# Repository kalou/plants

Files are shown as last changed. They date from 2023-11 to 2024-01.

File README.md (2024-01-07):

# Plants
*Plants monitoring and watering*

## Description

Plants is composed of:
* A sensor monitoring system and water pumps controller, written in Python, that
  runs on Linux, likely a Pi:
* Some [hardware](./hw) including a Raspberry Pi hat, switches and sensors.

## Features
### Supported sensors
* Support for ADS1115 ADC, to read voltage level sensors such as standard 555-based capacitive moisture sensors.
* Support for [chirp](https://github.com/Miceuz/i2c-moisture-sensor) i2c sensors, reading temperature and moisture.
### Watering
* Configuration and rule based watering:
  - Triggering watering based on sensor humidity percentage.
  - Watering limits per pump, persisted to disk.
* API to manually trigger watering.
### Metrics
* Export of sensor and pump data metrics to prometheus.
* API to poll running config and basic values.
## Example configuration
```
# Plants configuration

# For prometheus, and API, listen on public interface:
host: 0.0.0.0
port: 9191

# How frequently to poll
poll_interval: 5s

sensor_groups:
  -
    kind: 'chirp'   # Got a chirp for temp metrics
  -
    kind: 'ads1115'
    smbus: 1             # i2c BUS to reach the board, default 1 on rpi
    i2c_address: 72      # Address of the ADS1115
    enable_port: 9       # GPIO turning the group on
    sensors:
      - Dragon tail: &cap_sensor
          voltage_dry: 2.62 # This model has a better oscillator
          voltage_wet: 1.23 # and calibrates differently.
          port: 2
      #- Sensor 1: &bad555_cap_sensor
      #    <<: *cap_sensor
      #    voltage_dry: 2.05  # Than this one, where they used an
      #    voltage_wet: 0.95  # ne555.
      #    port: 2
      - Willows:
          <<: *cap_sensor
          port: 3
      - Small money trees:
          <<: *cap_sensor
          port: 1
      - Pothos:
          <<: *cap_sensor
          port: 0
  -
    kind: 'ads1115'
    smbus: 1             # i2c BUS to reach the board, default 1 on rpi
    i2c_address: 72      # Address of the ADS1115
    enable_port: 11      # GPIO turning the group on
    sensors:
      - Money tree:
          <<: *cap_sensor
          port: 3
      - Lemon tree:
          <<: *cap_sensor
          port: 2
      - Bonsai soil:
          <<: *cap_sensor
          port: 1
      - Parlor palm:
          <<: *cap_sensor
          port: 0

# If configured, pump history is saved across restarts
# in sqlite3 db. Otherwise, in-memory watering limits
# are used.
pumps_history_db: /var/lib/plants/plants_pumps_state.db

pumps:
  - Plants to the left:    # Pump 0
      kind: 'gpio'
      port: 10             # GPIO port activates pump on high
      duration: 20s        # Activate for 20s
      limits: &pump_limits
        - per_interval: 2w
          duration: 40s
        - per_interval: 300s
          duration: 20s
      activation_thresholds:
        - Money tree: 50% 
        - Pothos: 50% 
  - Shelf 1:               # Pump 1
      kind: 'gpio'
      port: 17
      duration: 20s
      limits: *pump_limits
      activation_thresholds:
        - Small money trees: 50%
        - Parlor palm: 50% 
  - Dragon tail:
      kind: 'gpio'         # Pump 2
      port: 22             # GPIO port activates pump on high
      duration: 20s
      limits: *pump_limits
      activation_thresholds:
        - Dragon tail: 50%  
  - Shelf 2:               # Pump 3 
      kind: 'gpio'
      port: 27             # GPIO port activates pump on high
      duration: 20s
      limits: *pump_limits
      activation_thresholds:
        - Lemon tree: 50%
        - Willows: 60%
```

## Developement
### Setup and local experiments
```
bash$ pip install -r requirements.txt
bash$ pip install --editable .
bash$ plants_server -c plants/plants.yaml
```
### Various helpers
```
bash$ python -m unittest discover plants
bash$ black plants # auto format
bash$ pylint plants
```


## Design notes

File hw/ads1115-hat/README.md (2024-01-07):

# Plants hat
*Disclaimer: I'm using this project to learn electronics. Use at your own risks and feel free
to reach out with suggestions.*

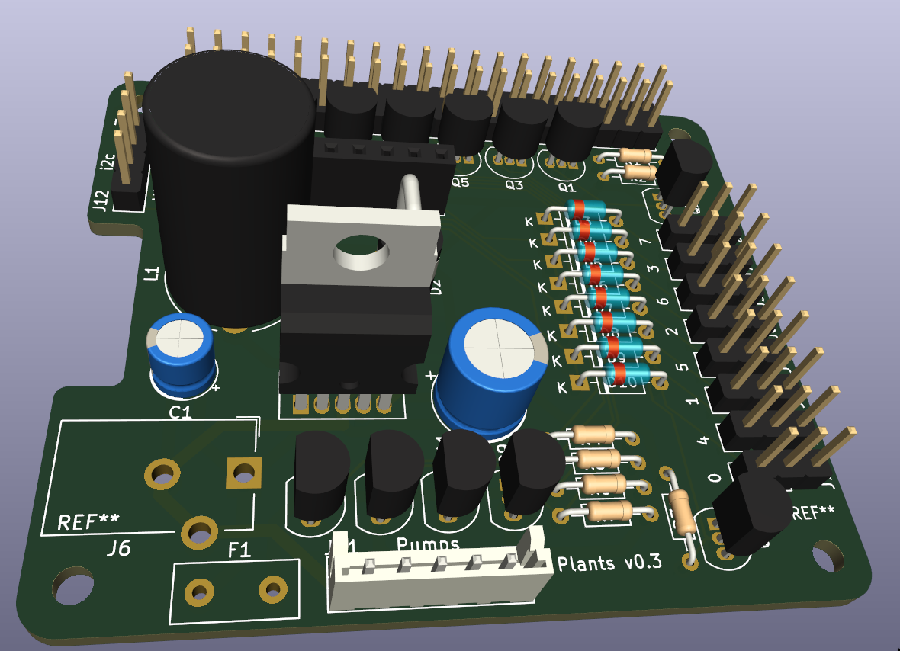
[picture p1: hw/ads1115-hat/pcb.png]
Overview of PCB

## Features
 * i2c ADS1115 ADC (+5v) and 8 sensor ports (pinout +5v,GND,out)
 * re-exports the i2c bus for more advanced sensors
 * powers 4 12v (water pumps, .. devices)
   * Transistors Q{5..8} and polyswitch fuse (also missing in the above 3d image) max current:
     *s8550*: .7A, *ss8550*: 1.5A, mosfets may be an option.
   * current tested setup uses 4.8w (400mA) pumps
 * 12v barrel jack (missing in the above 3d image) powers the pumps and an LM2576 that provides
   5v switched power to the Pi and sensors.
  * **WARNING** This project does **not** include a security diode on the +5v supply. When +12v
    is connected to the board, **no USB power should be plugged in**. Running a
    sensors-only board from USB power leaving the 12v barrel empty
    has not been tested but should work.

## Specifics
 * Sensor ports are divided in two groups of 4
   * Sensors 0,1,2,3 turn on with GPIO11
   * Sensors 4,5,6,7 turn on with GPIO9
   * Data should be read on ADS1115 AIN0,1,2,3
 * Pumps 0,1,2,3 are activated with GPIO17, GPIO27, GPIO22, GPIO10
   * Output JST pinout is GND,0,1,2,3
 * Polyfuse value needs to be adjusted - For 4.8w 240l/h 12v pumps, I use 400mA as it takes
   time to trip it.

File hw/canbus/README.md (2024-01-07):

## Canbus stuff
*Disclaimer: I'm using this project to learn electronics. Use at your own risks and feel free
to reach out with suggestions.*

### Sensors
Sensors are daisy chained on a low bitrate two-wires BUS
(using CANbus transceiver & protocol, at 20kbps).

Sensor circuit is an attiny85 coupled to an MCP2561.
 * +5v generic sensor + ADC
 * 12v 1A module (e.g. water pump, valve)
 * reset button

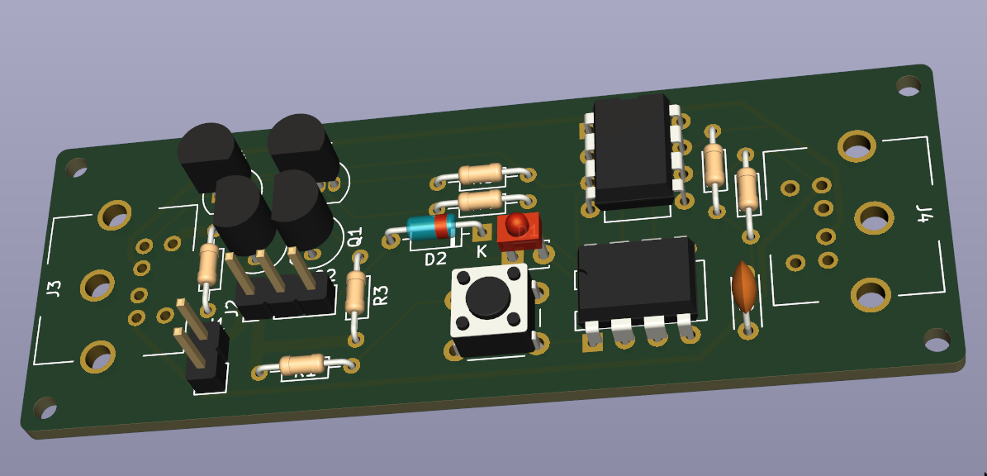
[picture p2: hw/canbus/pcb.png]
Overview of PCB


### CAN on the Pi
I use an MCP2515+TJA1050 module with an 8mhz crystal that talks SPI.
Connecting to Pi:
 * GPIO GPIO25(22) to INT, adding dtoverlay=mcp2515-can0,oscillator=8000000,interrupt=25
 * GPIO8(24) to CS
 * GPIO10(19) to MOSI
 * GPIO9(21) to MISO
 * GPIO11(23) to SCLK

### Hat
Future plans to build a +12v hat integrating CAN ports. Mini-DIN/6 (PS/2) ports?

### AVR programming and setup
On ubuntu linux:
```
sh$ git submodule init && git submodule update
sh$ sudo apt-get install avrdude avr-libc binutils-avr gcc-avr
sh$ cd avr && make && make avr-install
```

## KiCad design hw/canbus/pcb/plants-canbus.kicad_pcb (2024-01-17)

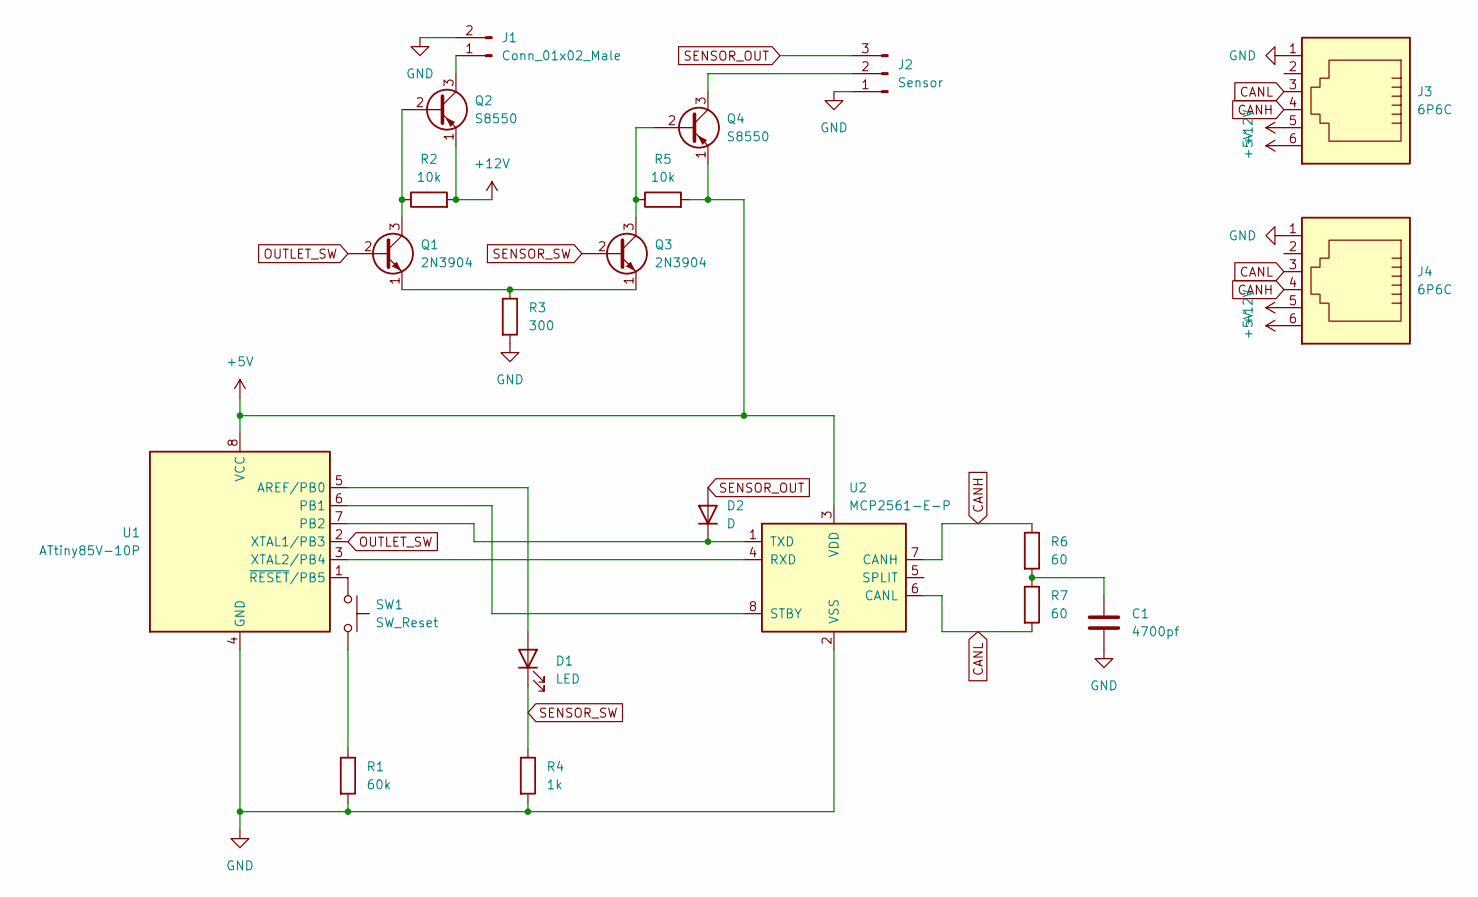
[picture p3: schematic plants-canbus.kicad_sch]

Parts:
C1: 4700pf; C_Disc_D4.3mm_W1.9mm_P5.00mm
D1: LED; LED_D1.8mm_W3.3mm_H2.4mm
D2: D; D_DO-35_SOD27_P7.62mm_Horizontal
J1: Conn_01x02_Male; PinHeader_1x02_P2.54mm_Vertical
J2: Sensor; PinHeader_1x03_P2.54mm_Vertical
J3, J4: 6P6C; RJ12_Pulse_E5566
Q1, Q3: 2N3904; TO-92_Inline
Q2, Q4: S8550; TO-92_Inline
R1: 60k; R_Axial_DIN0204_L3.6mm_D1.6mm_P7.62mm_Horizontal
R2, R5: 10k; R_Axial_DIN0204_L3.6mm_D1.6mm_P7.62mm_Horizontal
R3: 300; R_Axial_DIN0204_L3.6mm_D1.6mm_P7.62mm_Horizontal
R4: 1k; R_Axial_DIN0204_L3.6mm_D1.6mm_P7.62mm_Horizontal
R6, R7: 60; R_Axial_DIN0204_L3.6mm_D1.6mm_P7.62mm_Horizontal
SW1: SW_Reset; SW_PUSH_6mm
U1: ATtiny85V-10P; DIP-8_W7.62mm
U2: MCP2561-E-P; DIP-8_W7.62mm

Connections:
+5V: J3.6, J4.6, Q4.1 (E), R5.2, U1.8 (VCC), U2.3 (VDD)
+12V: J3.5, J4.5, Q2.1 (E), R2.2
CANH: J3.4, J4.4, R6.1, U2.7 (CANH)
CANL: J3.3, J4.3, R7.2, U2.6 (CANL)
GND: C1.2, J1.2, J2.1, J3.1, J4.1, R1.2, R3.2, R4.2, U1.4 (GND), U2.2 (VSS)
unnamed: C1.1, R6.2, R7.1
unnamed: D1.2 (A), U1.5 (AREF/PB0)
unnamed: D2.1 (K), U1.7 (PB2), U2.1 (TXD)
unnamed: J1.1, Q2.3 (C)
unnamed: J2.2, Q4.3 (C)
unnamed: Q1.1 (E), Q3.1 (E), R3.1
unnamed: Q1.3 (C), Q2.2 (B), R2.1
unnamed: Q3.3 (C), Q4.2 (B), R5.1
unnamed: R1.1, SW1.2
unnamed: SW1.1, U1.1 (~RESET/PB5)
unnamed: U1.3 (XTAL2/PB4), U2.4 (RXD)
unnamed: U1.6 (PB1), U2.8 (STBY)
OUTLET_SW: Q1.2 (B), U1.2 (XTAL1/PB3)
SENSOR_OUT: D2.2 (A), J2.3
SENSOR_SW: D1.1 (K), Q3.2 (B), R4.1

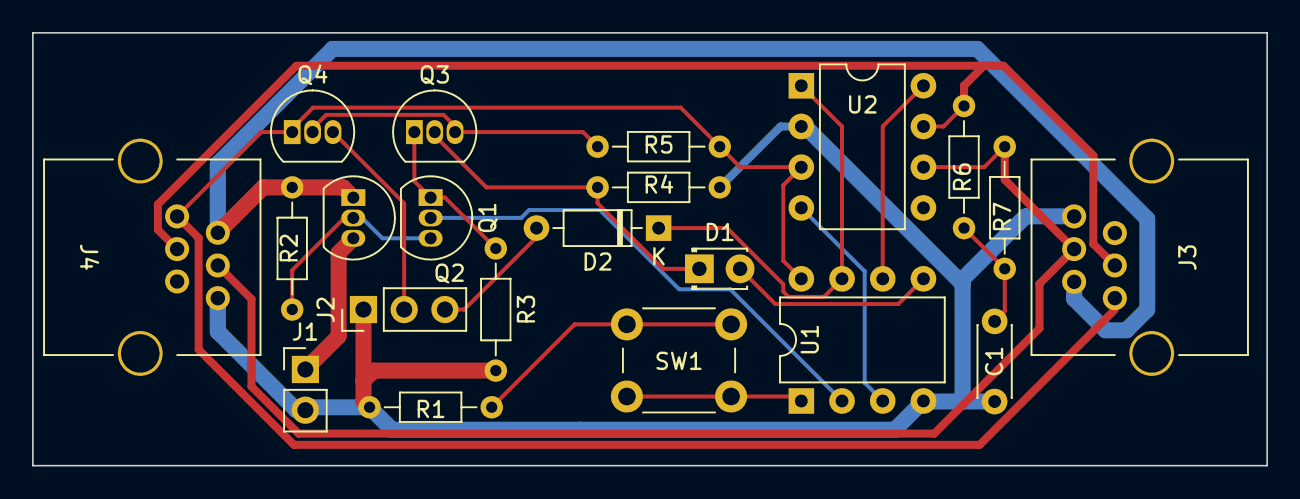
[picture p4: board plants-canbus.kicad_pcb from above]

Board: 2 copper layers, 77.0 x 27.0 mm, 21 parts (0 on the bottom side), 20 nets.

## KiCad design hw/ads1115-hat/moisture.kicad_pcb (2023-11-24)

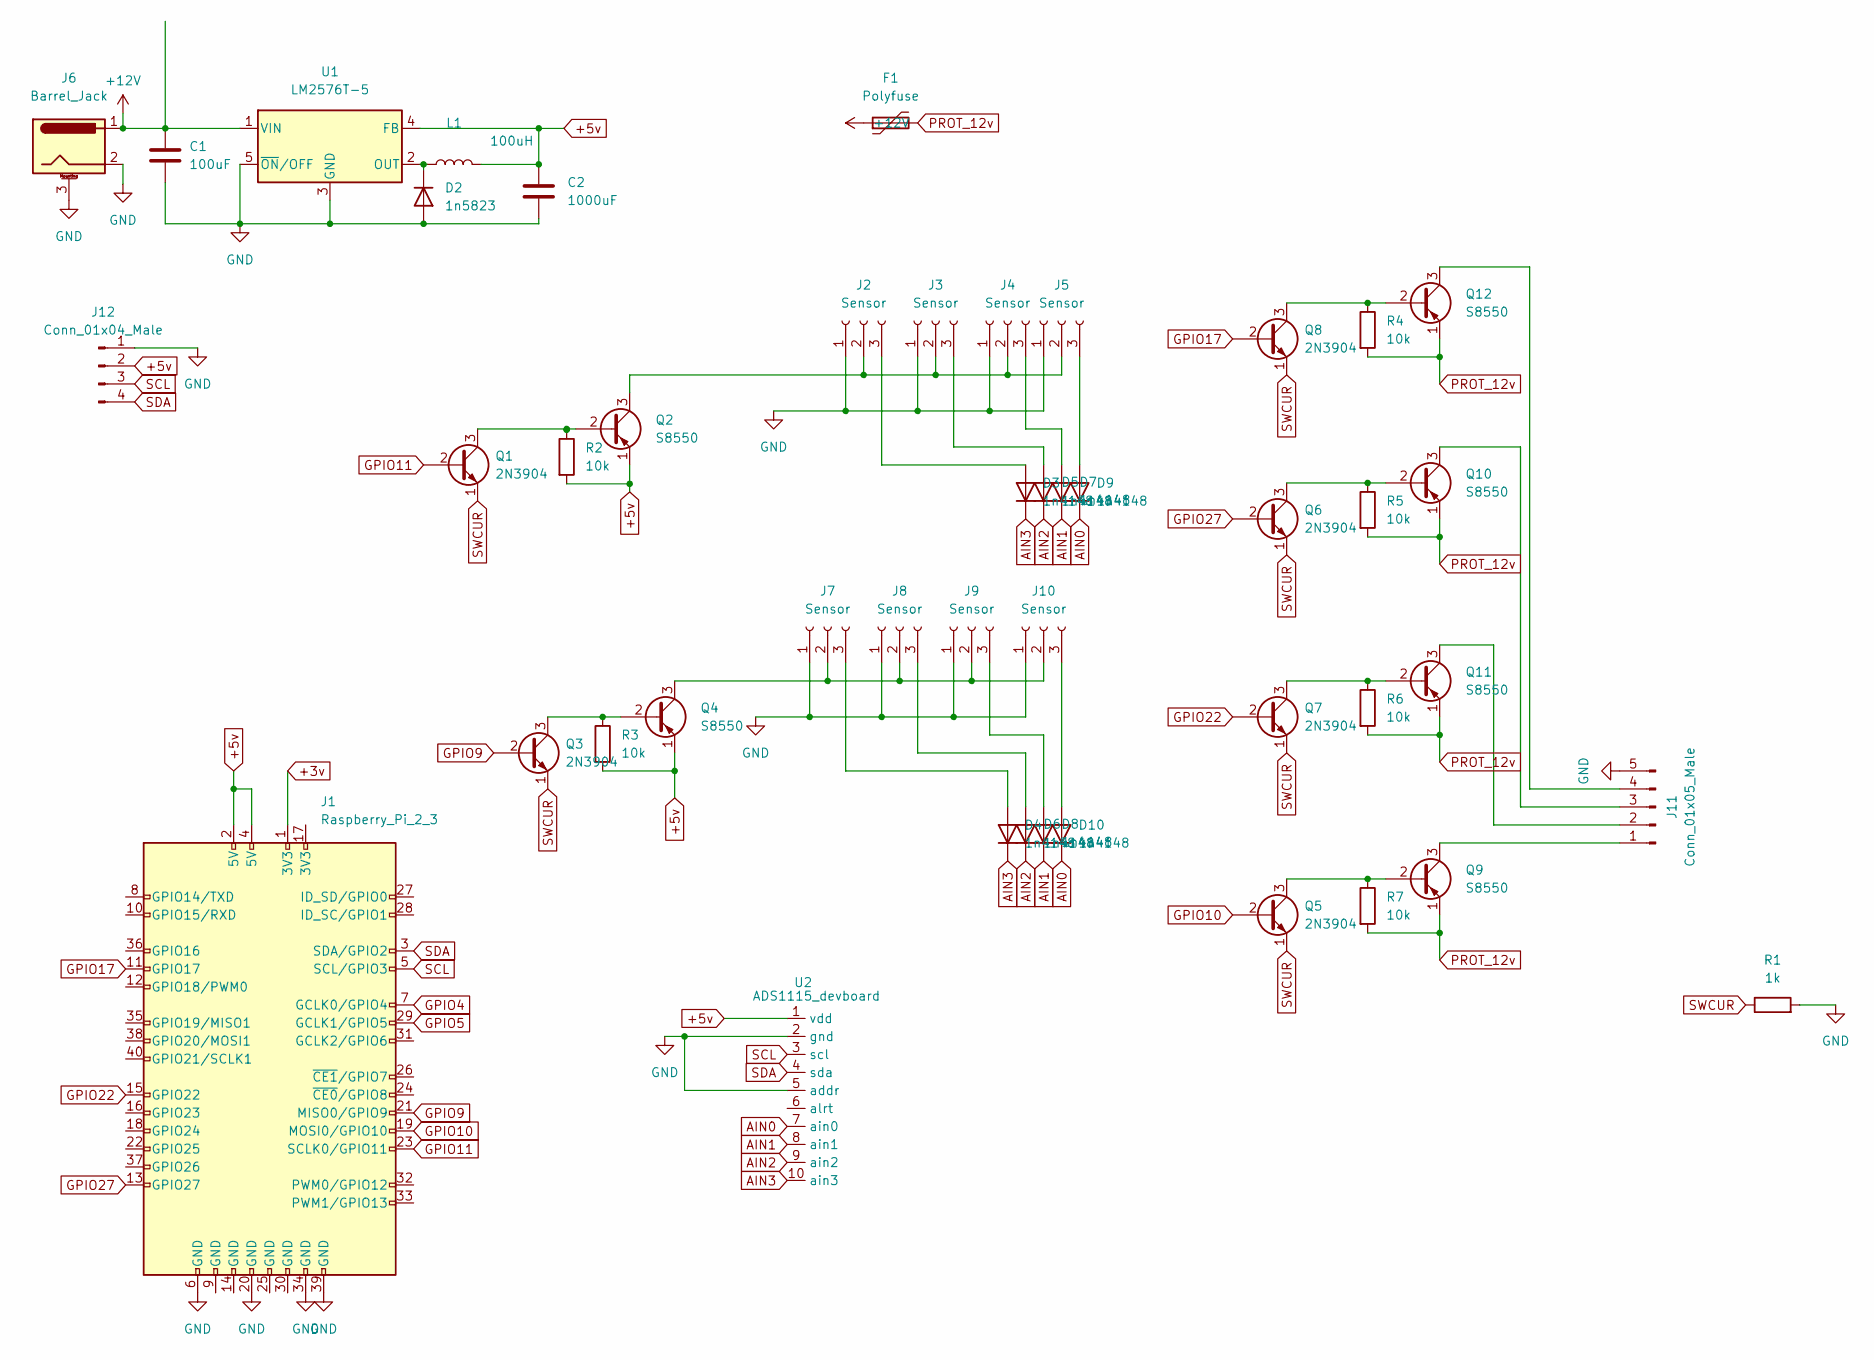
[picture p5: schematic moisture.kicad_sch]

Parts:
C1: 100uF; CP_Radial_D5.0mm_P2.50mm
C2: 1000uF; CP_Radial_D8.0mm_P2.50mm
D2: 1n5823; D_DO-201AD_P5.08mm_Vertical_KathodeUp
D3, D4, D5, D6, D7, D8, D9, D10: 1n4148; D_DO-35_SOD27_P7.62mm_Horizontal
F1: Polyfuse; Fuse_Littelfuse_395Series
J1: Raspberry_Pi_2_3; PinHeader_2x20_P2.54mm_Vertical
J2, J3, J4, J5, J7, J8, J9, J10: Sensor; PinHeader_1x03_P2.54mm_Vertical
J6: Barrel_Jack; BarrelJack_CUI_PJ-102AH_Horizontal
J11: Conn_01x05_Male; JST_EH_B5B-EH-A_1x05_P2.50mm_Vertical
J12: Conn_01x04_Male; PinHeader_1x04_P2.54mm_Vertical
L1: 100uH; L_Radial_D12.0mm_P10.00mm_Neosid_SD12_style1
Q1, Q3, Q5, Q6, Q7, Q8: 2N3904; TO-92_Inline
Q2, Q4, Q9, Q10, Q11, Q12: S8550; TO-92_Inline
R1: 1k; R_Axial_DIN0204_L3.6mm_D1.6mm_P7.62mm_Horizontal
R2, R3, R4, R5, R6, R7: 10k; R_Axial_DIN0204_L3.6mm_D1.6mm_P7.62mm_Horizontal
U1: LM2576T-5; TO-220-5_Vertical
U2: ADS1115_devboard; PinSocket_1x10_P2.54mm_Vertical

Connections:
+3v: J1.1 (3V3)
+5v: C2.1, J1.2 (5V), J1.4 (5V), J12.2, L1.2, Q2.1 (E), Q4.1 (E), R2.2, R3.2, U1.4 (FB), U2.1 (vdd)
+12V: C1.1, F1.1, J6.1, U1.1 (VIN)
AIN0: D9.1 (K), D10.1 (K), U2.7 (ain0)
AIN1: D7.1 (K), D8.1 (K), U2.8 (ain1)
AIN2: D5.1 (K), D6.1 (K), U2.9 (ain2)
AIN3: D3.1 (K), D4.1 (K), U2.10 (ain3)
GND: C1.2, C2.2, D2.2 (A), J1.6 (GND), J1.20 (GND), J1.34 (GND), J1.39 (GND), J2.1, J3.1, J4.1, J5.1, J6.2, J6.3 (MountPin), J7.1, J8.1, J9.1, J10.1, J11.5, J12.1, R1.2, U1.3 (GND), U1.5 (~ON/OFF), U2.2 (gnd), U2.5 (addr)
GPIO4: J1.7 (GCLK0/GPIO4)
GPIO5: J1.29 (GCLK1/GPIO5)
GPIO9: J1.21 (MISO0/GPIO9), Q3.2 (B)
GPIO10: J1.19 (MOSI0/GPIO10), Q5.2 (B)
GPIO11: J1.23 (SCLK0/GPIO11), Q1.2 (B)
GPIO17: J1.11 (GPIO17), Q8.2 (B)
GPIO22: J1.15 (GPIO22), Q7.2 (B)
GPIO27: J1.13 (GPIO27), Q6.2 (B)
unnamed: D2.1 (K), L1.1, U1.2 (OUT)
unnamed: D3.2 (A), J2.3
unnamed: D4.2 (A), J7.3
unnamed: D5.2 (A), J3.3
unnamed: D6.2 (A), J8.3
unnamed: D7.2 (A), J4.3
unnamed: D8.2 (A), J9.3
unnamed: D9.2 (A), J5.3
unnamed: D10.2 (A), J10.3
unnamed: J2.2, J3.2, J4.2, J5.2, Q2.3 (C)
unnamed: J7.2, J8.2, J9.2, J10.2, Q4.3 (C)
unnamed: J11.1, Q9.3 (C)
unnamed: J11.2, Q11.3 (C)
unnamed: J11.3, Q10.3 (C)
unnamed: J11.4, Q12.3 (C)
unnamed: Q1.3 (C), Q2.2 (B), R2.1
unnamed: Q3.3 (C), Q4.2 (B), R3.1
unnamed: Q5.3 (C), Q9.2 (B), R7.1
unnamed: Q6.3 (C), Q10.2 (B), R5.1
unnamed: Q7.3 (C), Q11.2 (B), R6.1
unnamed: Q8.3 (C), Q12.2 (B), R4.1
PROT_12v: F1.2, Q9.1 (E), Q10.1 (E), Q11.1 (E), Q12.1 (E), R4.2, R5.2, R6.2, R7.2
SCL: J1.5 (SCL/GPIO3), J12.3, U2.3 (scl)
SDA: J1.3 (SDA/GPIO2), J12.4, U2.4 (sda)
SWCUR: Q1.1 (E), Q3.1 (E), Q5.1 (E), Q6.1 (E), Q7.1 (E), Q8.1 (E), R1.1

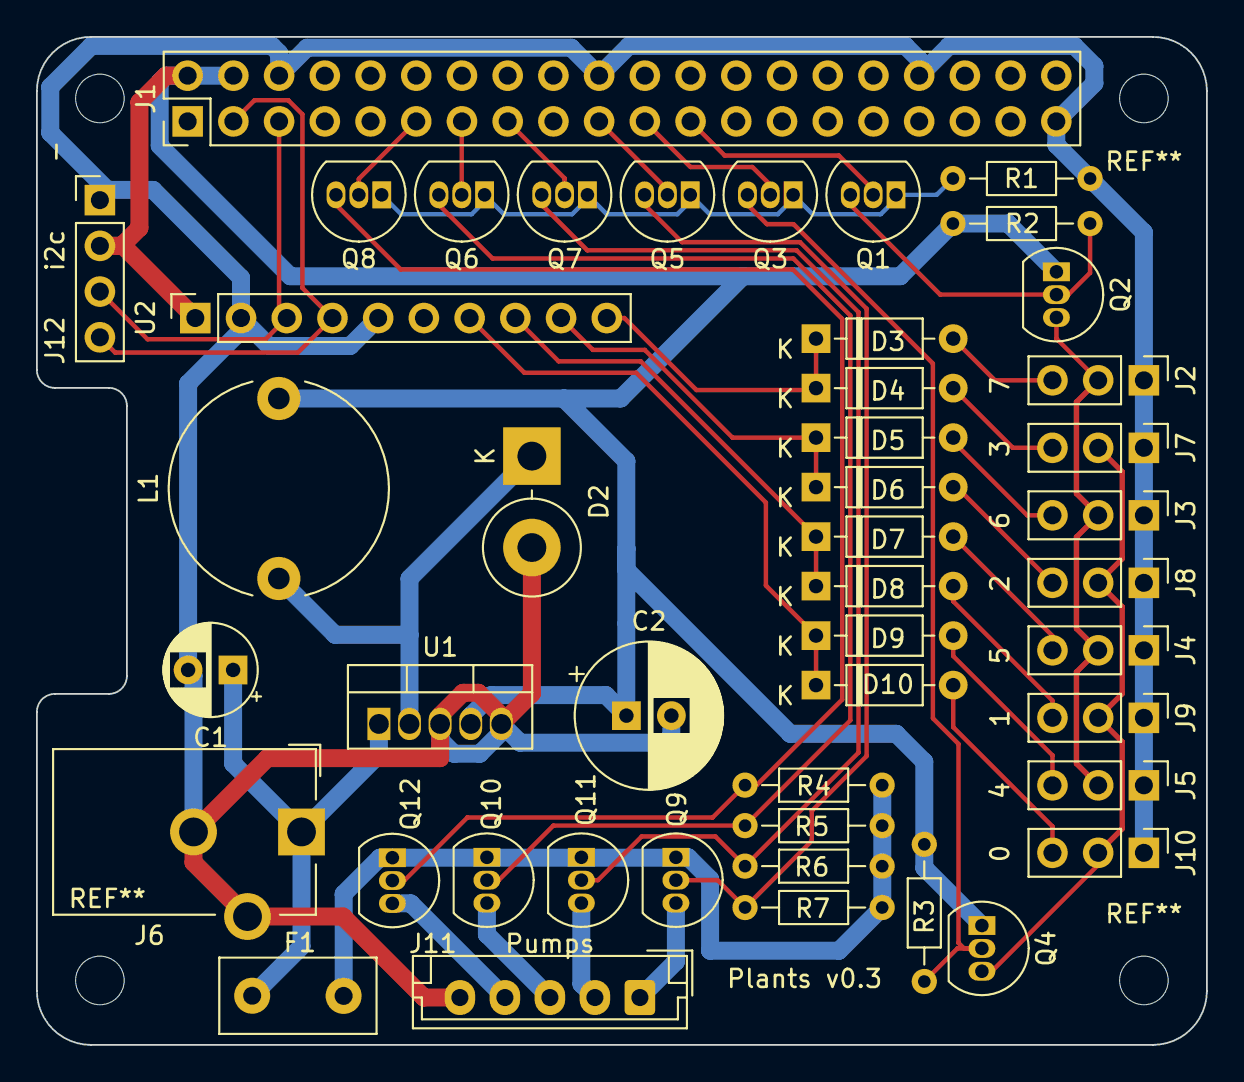
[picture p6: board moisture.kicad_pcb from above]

Board: 2 copper layers, 65.0 x 56.0 mm, 47 parts (0 on the bottom side), 38 nets.

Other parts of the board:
-: MountingHole_2.7mm_M2.5

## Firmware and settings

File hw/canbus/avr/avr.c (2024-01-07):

#include <avr/io.h>
#include <avr/interrupt.h>
#include <avr/sleep.h>

#include "can.h"
#include "plants.h"

// PB0, PDIP pin 5 turns on transistor to sensor's +5v.
// The sensor output is measured at ADC PB1 (ADC1), which
// is also the pin used for CAN transceiver TX by canbus.
#define DD_SENSOR_VCC (1 << DDB0)
#define P_SENSOR_VCC (1 << PB0)
#define SENSOR_on() do { PORTB |= P_SENSOR_VCC; } while(0)
#define SENSOR_off() do { PORTB &= ~P_SENSOR_VCC; } while(0)

#define DD_SWITCH_VCC (1 << DDB3)
#define P_SWITCH_VCC (1 << PB3)
#define SWITCH_on() do {  PORTB |= P_SWITCH_VCC; } while(0)
#define SWITCH_off() do {  PORTB &= ~P_SWITCH_VCC; } while(0)


static volatile bool adc_complete = false;
ISR(ADC_vect)
{
	adc_complete = true;
}

int16_t read_adc(int adc)
{
	int16_t reading, avg=0;

	/* Enable sleep mode, with ADC noise reduction,
	 * enable ADC and the ADC completion interrupt.
	 */
	MCUCR = (1<<SE) | (1<<SM0); 

	if (adc == 15) {
		// For temperature reading:
		// MUX[3:0] = 0b1111 selecting ADC4
		// REFS[2:0] = 0b010 selecting internal 1.1v ref
		ADMUX = (1<<REFS1) | 15;
	} else {
		// MUX[3:0] = 0b001, ADC1 (PB2)
		// REFS[2:0] = 0b000, Vcc reference
		ADMUX = adc & 3;
	}
	ADCSRA = (1<<ADEN) | (1<<ADIE) | (1<<ADIF) | 7; // Enable ADC, with interrupt, prescaler: ~60khz

	sei();

	// Perform moving average over 16 readings.
	for (int i = 0; i <16; i++) {
		adc_complete = false;
		sleep_cpu();
		while(!adc_complete);

		reading = ADCL;
		reading |= ADCH << 8;

		if (i == 0)
			avg = reading;
		else
			avg = avg + ((reading - avg) / (i+1));
	}

	// disable ADC to save power
	ADCSRA &= ~(1<<ADEN);

	return avg;
}

uint16_t read_temperature()
{
	return read_adc(15);
}

uint16_t read_sensor()
{
	SENSOR_on();
	// Disable transceiver and set TXD low for measure.
	STBY_high();
	DDRB &= ~(1<<DD_TXD);
	TXD_low();

	// Give sensor some warmup delay before we measure it.
	can_delay_ms(300);

	uint16_t v = read_adc(1);

	// Restore TXD & transceiver.
	SENSOR_off();
	TXD_high();
	DDRB |= (1<<DD_TXD);
	STBY_low();

	return v;
}

/* To turn RST port into a button without having
 * to reprogram the fuse, we use a well-known
 * divider trick.
 *
 * From datasheet R-rst is a pullup between 30k & 60k.
 * With a ~60k resistor to GND, approx 1/2 to 2/3 of
 * VCC should be on ADC0.
 */
bool is_button()
{
	uint16_t v = read_adc(0);
	return (v > 512 && v < 700);
}

bool check_reset_sequence()
{
	uint8_t cnt = 0;
	do {
		if (cnt++ > 200)
			return true;
	} while(is_button());
	return false;
}

void save_config(plants_config_t *conf)
{
	conf->crc = 0;
	conf->crc = compute_crc(conf, sizeof(conf));

	EECR = (0<<EEPM1)|(0<<EEPM0);
	for (int i = 0; i < sizeof(plants_config_t); i++) {
		EEAR = i;
		EEDR = *((char *) conf+i);
		EECR |= (1<<EEMPE);
		EECR |= (1<<EEPE);

		while (EECR & (1<<EEPE));
	}
}

bool load_config(plants_config_t *conf)
{
	char *p = (char *) conf;
	uint16_t crc;

	for (int i=0; i < sizeof(plants_config_t); i++) {
		EEAR = i;
		EECR |= (1<<EERE);
		*p++ = EEDR;
	}

	crc = conf->crc;
	conf->crc = 0;
	if (compute_crc(conf, sizeof(conf)) == crc)
		return true;
	return false;
}

void perform_reconfig(plants_config_t *conf)
{
	for(;;) {
		can_request(PLANTS_AUTOCONF_ID, 0);
		can_header_t *c = can_receive(200);
		if (c && c->rtr == 0) {
			blink();
			// This contains our ID
			conf->id = *((uint32_t *) c->data) & 0x1fffffff;
			// Attempt to publish to it. If we get an
			// ACK, we own it.
			if (can_send(conf->id, "random", 6) == 0) {
				save_config(conf);
				return;
			}
		}
		can_delay_ms(200);
	}
}

int main(void)
{
	plants_config_t conf;

	DDRB = DD_SENSOR_VCC | DD_SWITCH_VCC;

	// Disable digital input on TX and RST, used as ADC
	DIDR0 = (1<<ADC1D) | (1<<ADC0D);

	// Tiny power savings. Most savings
	// are done by sleeping.
	PRR |= (1<<PRTIM1) | (1<<PRUSI);

	can_init();

	if (!load_config(&conf)) {
		can_send(0x123, (char *) &conf, sizeof(conf));
		perform_reconfig(&conf);
	}

	for (;;) {
		can_header_t *c = can_receive(1000);

		if (c && c->len == 2 && c->data[0] == PLANTS_CMD_SWITCH) {
			switch(c->data[1]) {
				case PLANTS_CMD_SWITCH_ON:
					if (c->id == conf.id)
						SWITCH_on();
					break;
				case PLANTS_CMD_SWITCH_OFF:
					if (c->id == PLANTS_ALL_SENSORS_ID ||
					    c->id == conf.id)
						SWITCH_off();
					break;
			}
		}

		if (check_reset_sequence()) {
			DEBUG_high();
			perform_reconfig(&conf);
			DEBUG_low();
		}

		/* Read values and broadcast */
		uint16_t sensor_data = read_sensor();
		can_send(conf.id, (char *)&sensor_data, 2);
	}
}

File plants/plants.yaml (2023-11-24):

# Plants configuration

# Uncomment to listen on a public interace.
# host: 0.0.0.0
# Minimal API with pump control and /metrics for prometheus.
port: 9191

# Interval *between* polling rounds.
poll_interval: 5s

# Sensor groups implement hardware collecting from one or more
# sensors. 3 types are supported:
# - `ads1115` Supporting the ADS1115 4-ports ADC on i2c.
# - `mock-ads1115` Returning test data.
# - `chirp` An i2c device with temperature & moisture sensor
#           (https://github.com/Miceuz/i2c-moisture-sensor/)

sensor_groups:
  - kind: 'mock-ads1115'
    #smbus: 1             # i2c BUS to the ADS1115
    #i2c_address: 72      # Address of the ADS1115
    enable_port: 9        # If specified, this GPIO pin will be turned on
                          # and off during measurement.
    sensors:
      # Sensors can be named arbitrarily, but beware that we don't handle
      # collisions.
      - Pachira aquatica: &cap_sensor
          # This is how we define different sensors & calibrations:
          # Capacitive moisture sensors based on the TL555C chip
          # kind: 'moisture' is the only supported type now
          voltage_dry: 2.9
          voltage_wet: 1.5
          port: 0
      - Raphidophora decursiva: &ne555_cap_sensor
          # Capacitive moisture sensors based on a NE555
          voltage_dry: 2.05
          voltage_wet: 0.95
          port: 1
      - Willows:
          <<: *cap_sensor
          port: 2
      - Lemon tree:
          <<: *ne555_cap_sensor
          port: 3
  - kind: 'mock-ads1115'
    enable_port: 11
    sensors:
      - Orchid:
          <<: *cap_sensor
          port: 0
  - kind: 'chirp'            # This module provides a temperature and a
                             # moisture sensor. There's also a light sensor,
                             # which we don't support yet.
    #smbus: 1                # i2c bus
    #i2c_address: 0x20       # i2c address
    #name: "My other plant"  # defaults to chirp@<bus>:<address>
    #cap_wet: 500            # Capacitance value returned for 100% humidity.
    #cap_dry: 250            # Capacitance returned for 0% humidity.

# If configured, pump history is saved across restarts
# in sqlite3 db. Otherwise, in-memory watering limits
# are used.
#
# Don't keep /tmp which is usually erased at startup.
watering:
  pumps_history_db: /tmp/plants_pumps_state.db
  pumps:
    # Supported types are `gpio` (pin high to water) and the mock version.
    - Large pot:
        kind: 'mock-gpio'
        port: 9             # GPIO port activates pump on high
        duration: 20s       # A 4.8w 12v pump sends 240l/h
        limits:
          - per_interval: 2w   # Say this plant should be capped at one liter 
            duration: 35s      # per two weeks +/- priming.
          - per_interval: 300s # Let capillarity work before we add more.
            duration: 20s
        activation_thresholds:
          - Pachira aquatica: 30%  # Only if pachira at least 70% dry
    - Shelf:
        kind: 'mock-gpio'
        port: 10
        duration: 3s        # Activate shortly until probe is happy. Actual
                            # duration can be truncated by the limits.
        limits:
          - per_interval: 1w
            duration: 20s
          - per_interval: 15s
            duration: 5s
        activation_thresholds:
          - Willows: 60%      # I have two plants here, whenever both are
          - Lemon tree: 45%   # dry enough. Willows are more robust.

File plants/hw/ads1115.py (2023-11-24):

#!/usr/bin/python

import smbus
import time

# Valid addresses for ads1115
# Address[0] is with address pin to GND
addresses = [0b1001000, 0b1001001, 0b1001010, 0b1001011]


class Register:
    CONVERSION = 0
    CONFIG = 1
    LO_THRESH = 2
    HI_THRESH = 3


class Config:
    """
    Usage: Config.read(0) | Config.
    """

    # For ref from datasheet
    COMP_QUEUE = 0  # Comparator queue and disable - Requires setting
    # LO_THRESH and HI_THRESH registers.
    # 00: assert after one conversion, pin gets high after N comparisons
    # exceed the threshold
    # 01: after two
    # 10: after four
    # 11: disabled - pin is always high state
    COMP_LAT = 2  # latching comparator (alert/rdy latches at conversions)
    COMP_POL = 3  # comparator polarity (0: active low, 1: high)
    COMP_MODE = 4  # 0: traditional with hysteresis, 1: window
    DR = (
        5  # [7:5] Data rate for continuous: 0=8sps to 111=860sps - default 100 = 128s/s
    )
    DR_MASK = 7
    dr_to_rate = {0: 8, 1: 16, 2: 32, 3: 64, 4: 128, 5: 250, 6: 475, 7: 860}

    MODE = 8  # 1: single shot - 0: continuous conversion
    PGA = 9  # [11:9] PGA and amplifier config.
    PGA_MASK = 7
    pga_to_volts = {
        0: 6.144,
        1: 4.096,
        2: 2.048,
        3: 1.024,
        4: 0.512,
        5: 0.256,
        6: 0.256,
        7: 0.256,
    }

    MUX = 12  # [12:14] with ref to GND:
    # Esp 100 to 111 is AINx and GND
    OS = 15  # 0: no effect - 1: single conversion

    def __init__(self, value):
        self.value = value

    def to_bytes(self):
        return [(self.value >> 8) & 0xFF, self.value & 0xFF]

    @classmethod
    def from_bytes(self, b):
        return Config(int.from_bytes(b, byteorder="big"))

    @classmethod
    def single_shot_read_gnd(cls, x=0):
        """Emit config register to read single value from port AINx"""
        return Config(
            (1 << cls.OS)
            | ((0b100 | x) << cls.MUX)
            | (1 << cls.PGA)
            | (0b100 << cls.DR)  # 4.096v FSR
            | (1 << cls.MODE)  # DR=128 samples/second
            | (0b11 << cls.COMP_QUEUE)
        )

    def delay(self):
        return 1 / self.dr_to_rate[(self.value >> self.DR) & self.DR_MASK]

    def volts_range(self):
        return self.pga_to_volts[(self.value >> self.PGA) & self.PGA_MASK]

    def __eq__(self, other):
        return self.value == other.value

    def __repr__(self):
        return bin(self.value)


class ADC:
    def __init__(self, smbus_id, address):
        self.bus = smbus.SMBus(smbus_id)
        self.address = address

    def write_config(self, config):
        self.bus.write_i2c_block_data(self.address, Register.CONFIG, config.to_bytes())

    def read_config(self, wait_for=None):
        attempts = 0

        while conf := Config.from_bytes(
            self.bus.read_i2c_block_data(self.address, Register.CONFIG, 2)
        ):
            if not wait_for or (conf == wait_for):
                break
            time.sleep(wait_for.delay())
            attempts += 1
            if attempts > 3:
                raise Exception("Slow read %s!=%s" % (conf, wait_for))

        return conf

    def single_shot_read_gnd(self, x):
        # Write to config register
        config = Config.single_shot_read_gnd(x)
        self.write_config(config)

        # Check it's there
        conf = self.read_config(wait_for=config)

        # Read conversion register (two bytes, MSB/LSB)
        reg = self.bus.read_i2c_block_data(self.address, Register.CONVERSION, 2)

        # This is a 16 bits signed adc
        return (
            conf.volts_range()
            * int.from_bytes(reg, byteorder="big", signed=True)
            / 32768
        )


if __name__ == "__main__":
    print("Test write for read-ain0 is %s\n", bin(Config.single_shot_read_gnd(0)))

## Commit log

2024-01-07 Proto for ATtiny85 CAN sensors+switches
    [moisture.kicad_pcb, moisture.kicad_sch, plants-canbus.kicad_pcb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]
2024-01-17 Replace PS/2 connector with RJ12
    [plants-canbus.kicad_pcb, plants-canbus.kicad_sch]
